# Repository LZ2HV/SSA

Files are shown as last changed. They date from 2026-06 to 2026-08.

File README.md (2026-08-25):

	
 Start-Stop memory Module for MQB platforms as VW: T-CROSS, T-ROC, Polo, Taigo.<br/>
 With: PIC16F684 or PIC16F676 or PIC12F683 or PIC12F675, from Microchip and similar. 
 
Requirements to compile and understanding:
1. Compilator, CCS PCWHD v5.115.
2. SCH, Autodesk EAGLE v9.6.1.
3. Simulator for testing, Proteus Professional v8.13.
4. For writing into PIC, PICkit2 or PICkit3.<br/>
For PIC16F684 HEX is "mssa_pic16f684.hex", for PIC12F683 HEX is "mssa_pic12f683.hex",<br/>
for PIC16F676 HEX is "mssa_pic16f676.hex", for PIC12F675 HEX is "mssa_pic12f675.hex".

Connections: For T-Cross (Switch module 1 in centre console, module EX23, 10 pins connector black),
1. LED = PWM signal 200Hz duty cycle 5-90%, and or DC (12V) signal, from Start/Stop LED, (pin 6).
2. BUT = Button Start/Stop (pin 3).
3. 12V = KL15, ignition (pin 9).
4. GND = GND (pin 1).

How its work:
1. If Start/Stop System is switched to off from ((A) car button), this state will be saved after 1sec.
2. If Start/Stop System is switched to on from ((A) car button), this state will be saved after 4sec.
3. At start ignition saved (Start/Stop System is off) will be returned after 6sec (6sec is default value).
4. If you wanna to change this 6sec, just push once button in the module, module LED, will be flashing 7 times = 7sec,
next bush of the button, will be change to 8sec, module LED, will be flashing 8 times ... (2 to 8sec).
5. Main cicle of the device is indicated from module LED, every 3sec one short flashing.

Schematics and boards is in directory "sch", thers have three variants, two with DIP socket one with SMD elements,
 in down pictures is presented variant with SMD elements (directory sch/smd). 
 
<strong>Important: If you are not tech savvy, do not attempt this.</strong><br/><br/>
<strong>An important part of the circuits is the PWM and DC detector shown in the picture below.</strong><br/>.
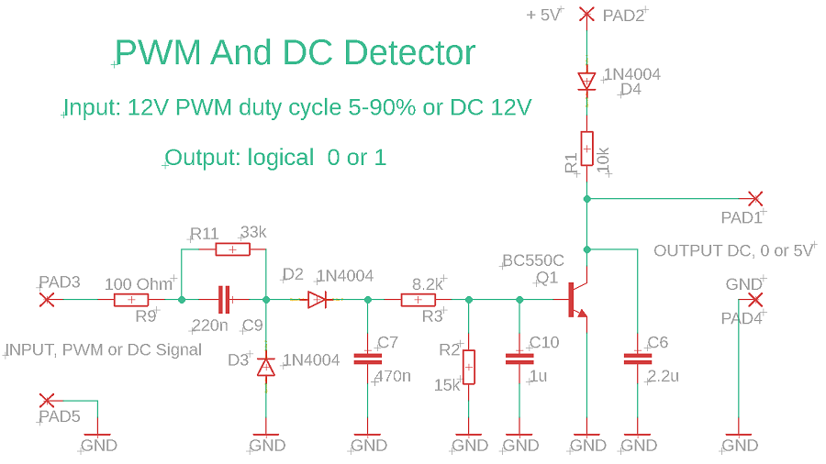
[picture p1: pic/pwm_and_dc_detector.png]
Detector
<br/>

<strong>SMD variant: Gerber file sch/smd/mssaPIC12smd_2026-07-19.zip</strong>
1. All zero resistors are not placed at the beginning (R9, R13, R14).
2. Resistor R9 are placed after successfully programming.  
3. If Button Start-Stop work with GND (T-Cross) Add R14, Remove R10 and R13.
4. If Button Start-Stop work with Plus (some Skoda models) Add R13, Remove R14.<br/>
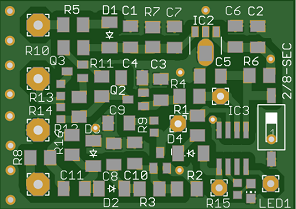
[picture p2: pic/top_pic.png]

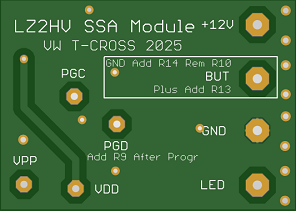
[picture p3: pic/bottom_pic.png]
Bottom
<br/>
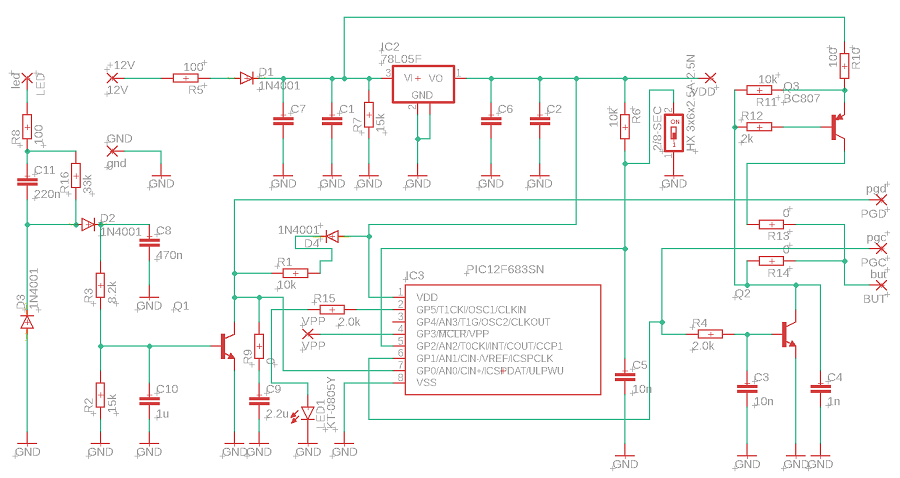
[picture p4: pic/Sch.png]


<strong>DIP PIC12 variant: Gerber file sch/mssaPIC12_2026-07-19.zip, This variant work only for Button with GND.</strong><br/>
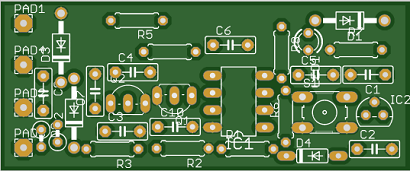
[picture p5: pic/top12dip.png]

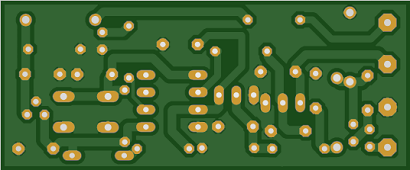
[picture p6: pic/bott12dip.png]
<br/>
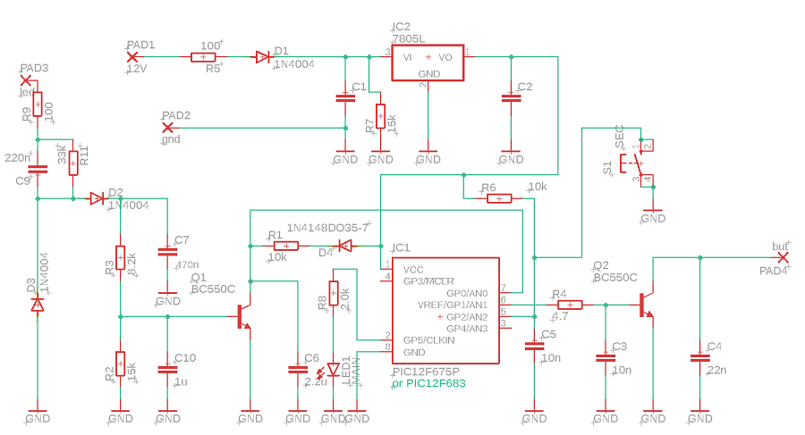
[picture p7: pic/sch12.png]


<strong>DIP PIC16 variant: Gerber file sch/mssaPIC16_2026-07-19.zip, This variant work only for Button with GND.</strong><br/>
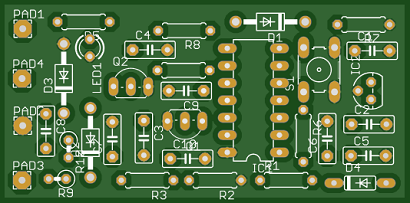
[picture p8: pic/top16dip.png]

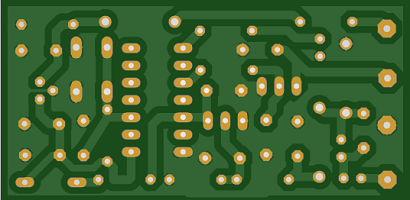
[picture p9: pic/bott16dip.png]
<br/>
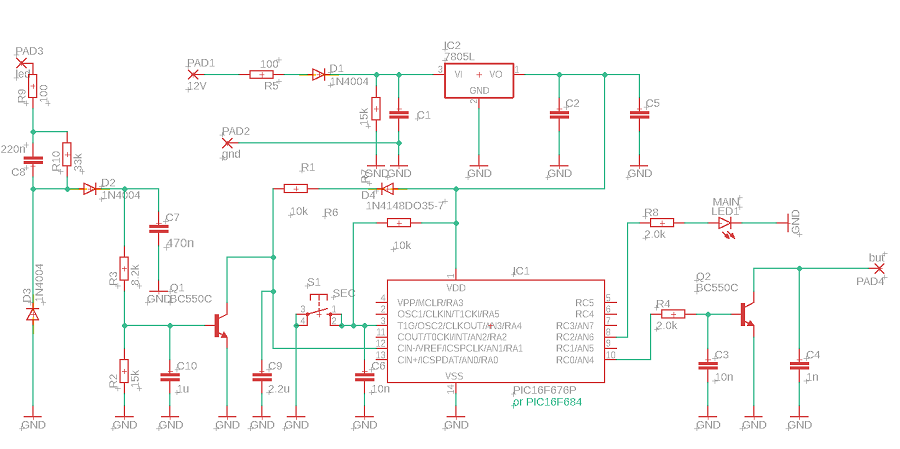
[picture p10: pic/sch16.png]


<strong>First prototype with pic16: In My VW T-Cross 2025</strong><br/>
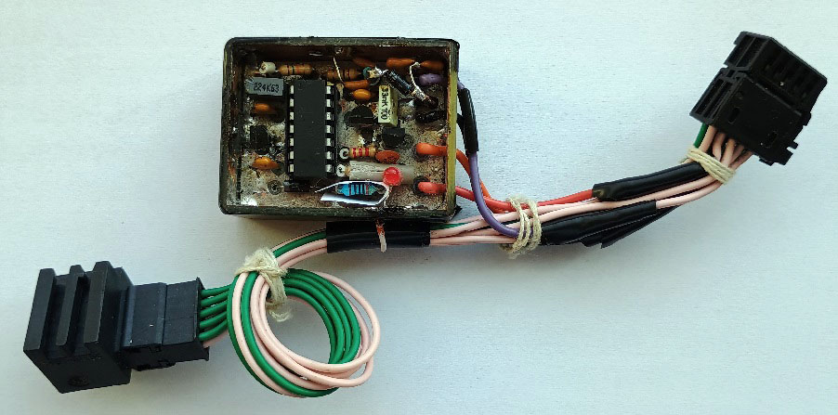
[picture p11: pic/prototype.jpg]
<br/>
<strong>Second prototype with pic12:</strong><br/>
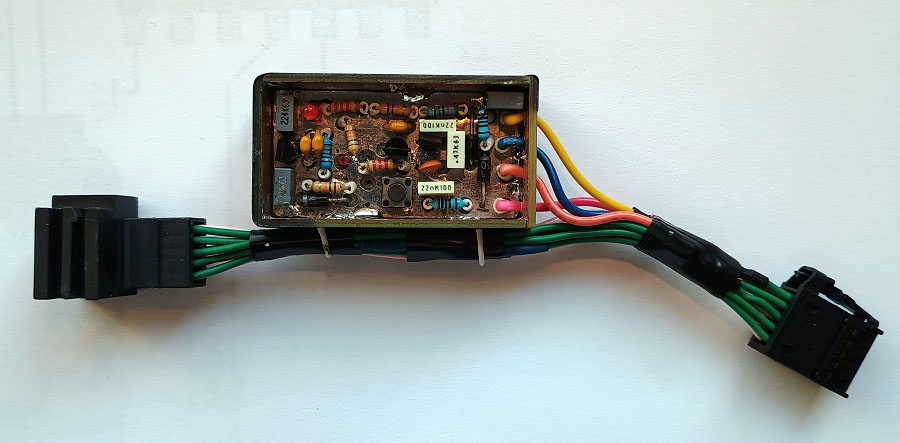
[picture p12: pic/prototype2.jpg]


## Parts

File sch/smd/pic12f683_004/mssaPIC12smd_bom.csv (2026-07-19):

Comment | Designator | Footprint | LCSC Part #
0 | R9 R13 R14 | R0603
1N4001 | D1 D2 D3 D4 | SOD-123_MINI-SMA
1n | C4 | C1206K
1u | C10 | C1206K
2.0k | R4 | M1206
2.0k | R15 | R0603
2.2u | C9 | C1206K
2k | R12 | M1206
8.2k | R3 | M1206
10k | R1 R6 R11 | M1206
10n | C3 C5 | C1206K
12V | +12V | 3 17/1 3
15k | R2 R7 | M1206
33k | R16 | M1206
78L05F | IC2 | SOT89
100 | R5 R8 R10 | M1206
100n | C1 C6 C7 | C1206K
220n | C2 C11 | C1206K
470n | C8 | C1206K
BC807 | Q3 | SOT23-BEC
BC817 | Q1 Q2 | SOT23-BEC
HX 3x6x2.5A-2.5N | 2/8-SEC | SMS-001
KT-0805Y | LED1 | CHIP-LED0805
PIC12F683SN | IC3 | SO-08
VDD | VDD | 2 15/1 0
VPP | VPP | 2 15/1 0
but | BUT | 3 17/1 3
gnd | GND | 3 17/1 3
led | LED | 3 17/1 3
pgc | PGC | 2 15/1 0
pgd | PGD | 2 15/1 0

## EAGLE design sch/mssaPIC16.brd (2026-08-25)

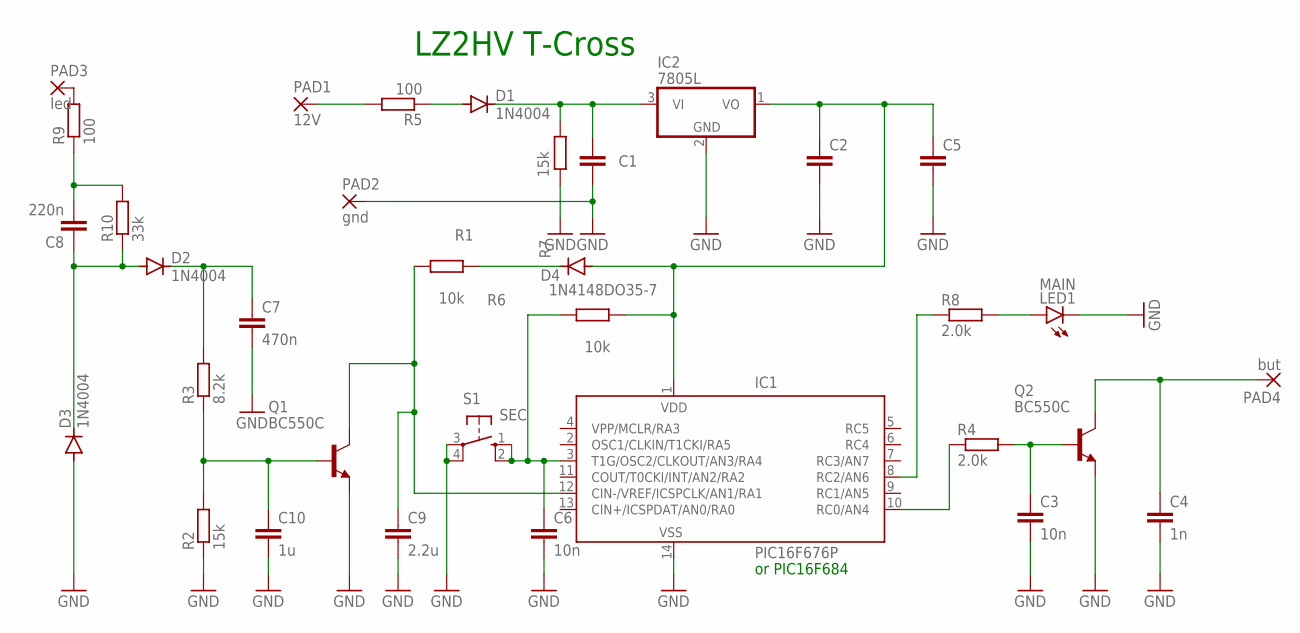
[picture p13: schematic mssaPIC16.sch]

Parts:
C1: 100n; C5B2.5
C2: 101n; C5B2.5
C3, C6: 10n; C5B2.5
C4: 1n; C5B2.5
C5, C8: 220n; C5B2.5
C7: 470n; C5B2.5
C9: 2.2u; C5B2.5
C10: 1u; C5B2.5
D1, D2, D3: 1N4004; DO41-10
D4: 1N4148DO35-7; DO35-7
IC1: PIC16F676P; DIL14
IC2: 7805L; TO92
LED1: MAIN; LED3MM
PAD1: 12V; 2,54/1,0
PAD2: gnd; 2,54/1,0
PAD3: led; 2,54/1,0
PAD4: but; 2,54/1,0
Q1, Q2: BC550C; TO92-EBC
R1, R6: 10k; 0207/7
R2, R7: 15k; 0207/7
R3: 8.2k; 0207/7
R4, R8: 2.0k; 0207/7
R5: 100; 0207/7
R9: 100; 0207/2V
R10: 33k; 0207/2V
S1: SEC; B3F-10XX

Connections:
GND: C1.2, C2.2, C3.2, C4.2, C5.2, C6.2, C7.2, C9.2, C10.2, D3.A, IC1.14 (VSS), IC2.2 (GND), LED1.K (C), PAD2.1, Q1.E, Q2.E, R2.1, R7.1, S1.3, S1.4 (P1)
unnamed: C1.1, D1.C, IC2.3 (VI), R7.2
unnamed: C2.1, C5.1, D4.A, IC1.1 (VDD), IC2.1 (VO), R6.2
unnamed: C10.1, Q1.B, R2.2, R3.1
unnamed: C9.1, IC1.12 (CIN-/VREF/ICSPCLK/AN1/RA1), Q1.C, R1.1
unnamed: PAD1.1, R5.2
unnamed: IC1.10 (RC0/AN4), R4.1
unnamed: C3.1, Q2.B, R4.2
unnamed: C4.1, PAD4.1, Q2.C
unnamed: C7.1, D2.C, R3.2
unnamed: D1.A, R5.1
unnamed: C6.1, IC1.3 (T1G/OSC2/CLKOUT/AN3/RA4), R6.1, S1.1 (S), S1.2 (S1)
unnamed: C8.2, R9.1, R10.2
unnamed: C8.1, D2.A, D3.C, R10.1
unnamed: LED1.A, R8.2
unnamed: IC1.8 (RC2/AN6), R8.1
unnamed: D4.C, R1.2
unnamed: PAD3.1, R9.2

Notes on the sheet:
LZ2HV T-Cross
or PIC16F684

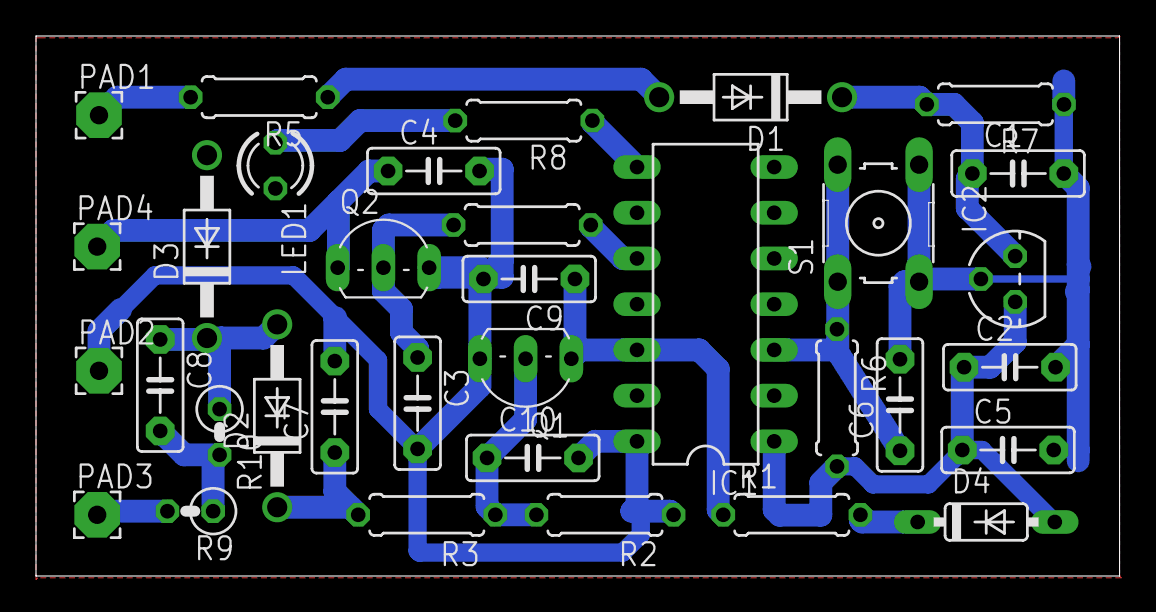
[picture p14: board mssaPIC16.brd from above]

Board: 2 copper layers, 60.2 x 30.0 mm, 34 parts (0 on the bottom side), 18 nets.

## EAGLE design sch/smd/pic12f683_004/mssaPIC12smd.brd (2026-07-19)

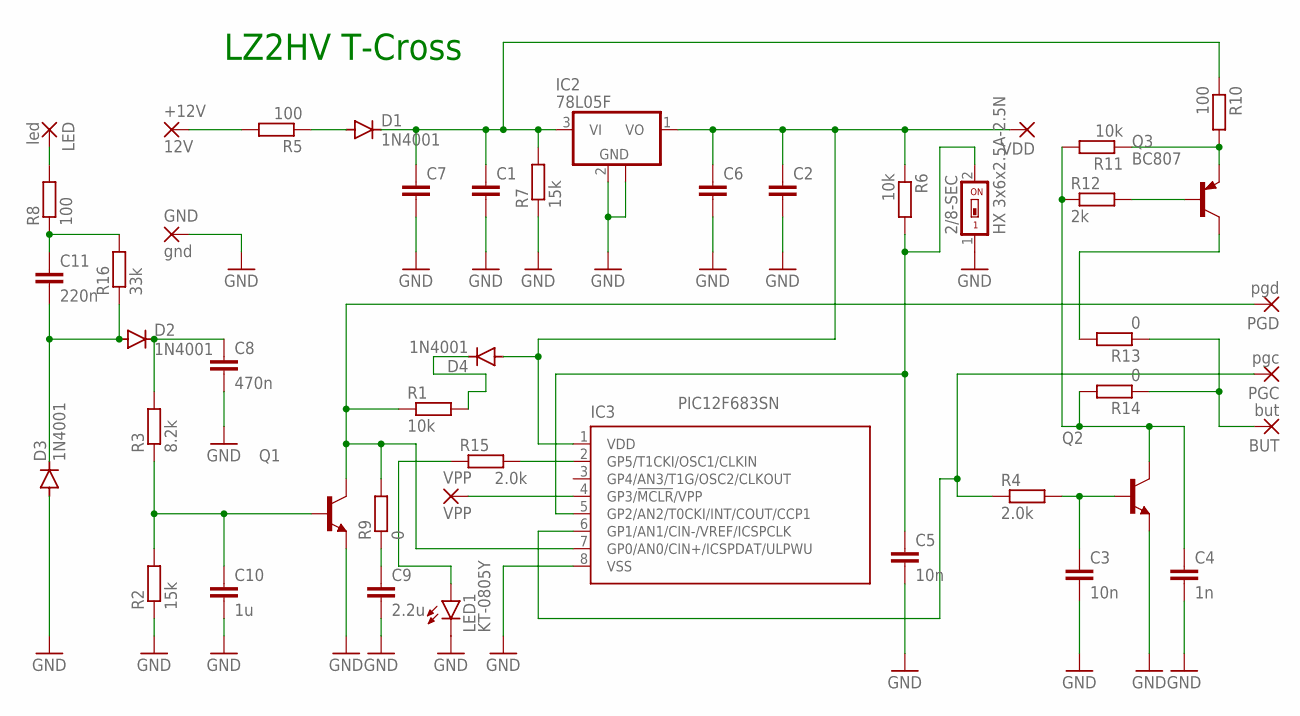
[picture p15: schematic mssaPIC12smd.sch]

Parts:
2/8-SEC: HX 3x6x2.5A-2.5N; SMS-001
+12V: 12V; 3,17/1,3
BUT: but; 3,17/1,3
C1, C6, C7: 100n; C1206K
C2, C11: 220n; C1206K
C3, C5: 10n; C1206K
C4: 1n; C1206K
C8: 470n; C1206K
C9: 2.2u; C1206K
C10: 1u; C1206K
D1, D2, D3, D4: 1N4001; SOD-123_MINI-SMA
GND: gnd; 3,17/1,3
IC2: 78L05F; SOT89
IC3: PIC12F683SN; SO-08
LED: led; 3,17/1,3
LED1: KT-0805Y; CHIP-LED0805
PGC: pgc; 2,15/1,0
PGD: pgd; 2,15/1,0
Q1, Q2: BC817; SOT23-BEC
Q3: BC807; SOT23-BEC
R1, R6, R11: 10k; M1206
R2, R7: 15k; M1206
R3: 8.2k; M1206
R4: 2.0k; M1206
R5, R8, R10: 100; M1206
R9, R13, R14: 0; R0603
R12: 2k; M1206
R15: 2.0k; R0603
R16: 33k; M1206
VDD: VDD; 2,15/1,0
VPP: VPP; 2,15/1,0

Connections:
GND: 2/8-SEC.1, C1.2, C2.2, C3.2, C4.2, C5.2, C6.2, C7.2, C8.2, C9.2, C10.2, D3.A, GND.1, IC2.2 (GND), IC2.2@1 (GND), IC3.8 (VSS), LED1.C, Q1.E, Q2.E, R2.1, R7.1
unnamed: C1.1, C7.1, D1.C, IC2.3 (VI), R7.2, R10.1
unnamed: C11.2, D2.A, D3.C, R16.1
unnamed: C10.1, Q1.B, R2.2, R3.1
unnamed: IC3.7 (GP0/AN0/CIN+/ICSPDAT/ULPWU), PGD.1, Q1.C, R1.1, R9.2
unnamed: +12V.1, R5.2
unnamed: IC3.6 (GP1/AN1/CIN-/VREF/ICSPCLK), PGC.1, R4.1
unnamed: C3.1, Q2.B, R4.2
unnamed: C4.1, Q2.C, R11.2, R12.1, R14.2
unnamed: C8.1, D2.C, R3.2
unnamed: D1.A, R5.1
unnamed: IC3.4 (GP3/!MCLR!/VPP), VPP.1
unnamed: 2/8-SEC.2, C5.1, IC3.5 (GP2/AN2/T0CKI/INT/COUT/CCP1), R6.2
unnamed: C11.1, R8.1, R16.2
unnamed: LED.1, R8.2
unnamed: C9.1, R9.1
unnamed: Q3.E, R10.2, R11.1
unnamed: Q3.C, R13.2
unnamed: Q3.B, R12.2
unnamed: BUT.1, R13.1, R14.1
unnamed: IC3.2 (GP5/T1CKI/OSC1/CLKIN), R15.2
unnamed: LED1.A, R15.1
unnamed: D4.C, R1.2
VDD: C2.1, C6.1, D4.A, IC2.1 (VO), IC3.1 (VDD), R6.1, VDD.1

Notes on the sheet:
LZ2HV T-Cross

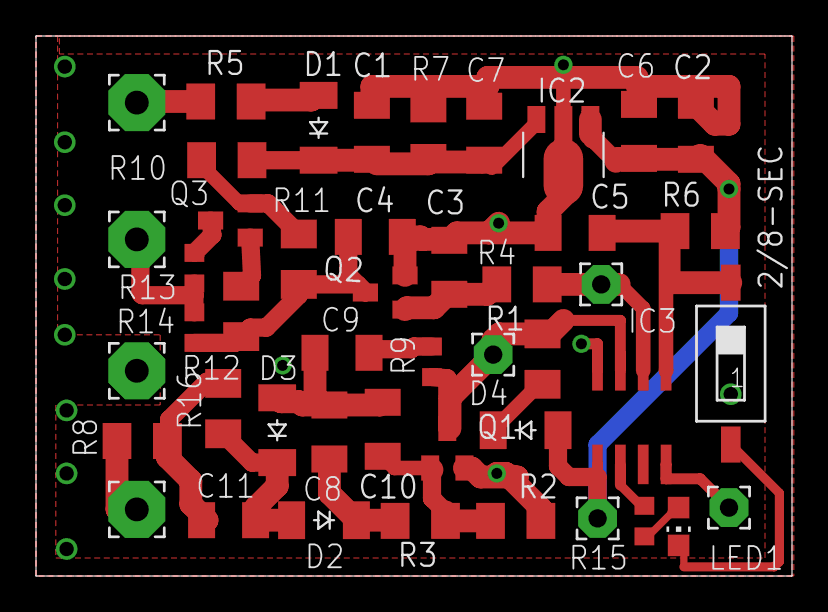
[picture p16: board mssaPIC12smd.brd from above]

Board: 2 copper layers, 42.0 x 30.0 mm, 46 parts (0 on the bottom side), 24 nets.

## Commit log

2026-06-17 SSA v.024
    [mssaPIC12.brd, mssaPIC12.sch, mssaPIC12smd.brd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]
2026-07-03 SSA v.034
    [mssaPIC12.brd, mssaPIC12.sch, mssaPIC16.brd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]
